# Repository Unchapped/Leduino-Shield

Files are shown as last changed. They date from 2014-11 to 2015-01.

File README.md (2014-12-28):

Leduino Shield
=======
The Leduino shield is a high-current PWM driver for commonly available 12V Tri-color LED strips and Modules. It is based on the [Adafruit PWM Servo Shield](http://www.adafruit.com/product/1411) and is compatible with their drivers. Some Library components were also sourced from the Sparkfun EAGLE Libraries.

Links
======
* [Adafruit Shield PCB](/adafruit/Adafruit-16-channel-PWM-Servo-Shield/)
* [Adafruit PWM Library](/adafruit/Adafruit-PWM-Servo-Driver-Library)
* [Adafruit EAGLE Library](/adafruit/Adafruit-Eagle-Library)
* [Sparkfun EAGLE Library](/sparkfun/SparkFun-Eagle-Libraries)

License
======
<br /><span xmlns:dct="http://purl.org/dc/terms/" property="dct:title">Leduino Shield</span> by <a xmlns:cc="http://creativecommons.org/ns#" href="https://github.com/Unchapped/Leduino" property="cc:attributionName" rel="cc:attributionURL">Nathaniel Chapman</a> is licensed under a <a rel="license" href="http://creativecommons.org/licenses/by-sa/4.0/">Creative Commons Attribution-ShareAlike 4.0 International License</a>.<br />Based on a work by <a xmlns:dct="http://purl.org/dc/terms/" href="http://www.adafruit.com/product/1411" rel="dct:source">Adafruit Industries</a>.

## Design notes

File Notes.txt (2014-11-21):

External Driver setup in PCA9685 datasheet table 11
Using setup [3] with NMOS drivers, no pullup resistors needed.

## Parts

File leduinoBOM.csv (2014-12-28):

Part | Value | Device | Package | Description | Qty/board | Digikey PN | Digikey Cost | Cost/Board
C1-2 | 10uF | CAP_POL1206 | EIA3216 | Capacitor Polarized | 2 | 1276-1804-1-ND | $0.34 | $0.68
C3 | .1uF | C-USC0805 | C0805 | CAPACITOR, American symbol | 2 | 1276-1099-1-ND | $0.10 | $0.20
JP1/2 | M023.5MM | M04-3.5MM | SCREWTERMINAL-3.5MM-4 |  | 1 | ED2637-ND | $0.73 | $0.73
JP4-7 |  | PINHD-1X63.5MM-RA | 1X06-3.5M-RA | TERM BLOCK HDR 6POS R/A 3.5MM | 4 | WM7774-ND | $1.54 | $6.16
JP4-7 | (Mating Conn) | PINHD-1X63.5MM-RA | 1X06-3.5M-RA | TERM BLOCK PLUG 6POS STR 3.5MM | 4 | WM7736-ND | $2.24 | $8.96
RN1-2 | 10K | 4R-NEXB38V | EXB38V | Array Chip Resistor | 2 | Y9103CT-ND | $0.12 | $0.24
S1 | SHIELD | PINHD-1x40-0.1" | CONN HEADR BRKWAY .100 40POS STR |  | 1 | A32701-40-ND | $3.01 | $3.01
U1 | MIC39100-5.0WS | V_REG_LDOSMD | SOT-223 | Voltage Regulator LDO | 1 | 576-1173-ND | $1.66 | $1.66
U2 |  | PCA9685 | TSSOP28 | PCA9685 - 16 Channel 12-Bit I2C PWM Controller | 1 | 568-8366-5-ND | $2.36 | $2.36
U3-10 | DMN6040SSD | DMN6040SSD | SO8 | MOSFET 2N-CH 60V 5A 8SO | 8 | DMN6040SSD-13DICT-ND | $0.46 | $3.68
 |  |  |  |  |  |  | Total: | $27.68
SOL |  |  | SOLDER PASTE NO-CLEAN LF 5CC SYR | Solder Paste |  | SMD291SNL-ND | $15.30
FLUX |  |  | TACK FLUX 10CC WATER WASHABLE | Solder Flux, Organic |  | SMD4300TF10-ND | $14.93
BRAID |  |  | BRAID ROSIN GOLD .050"X5' | Solder Braid |  | EB1087-ND | $2.77

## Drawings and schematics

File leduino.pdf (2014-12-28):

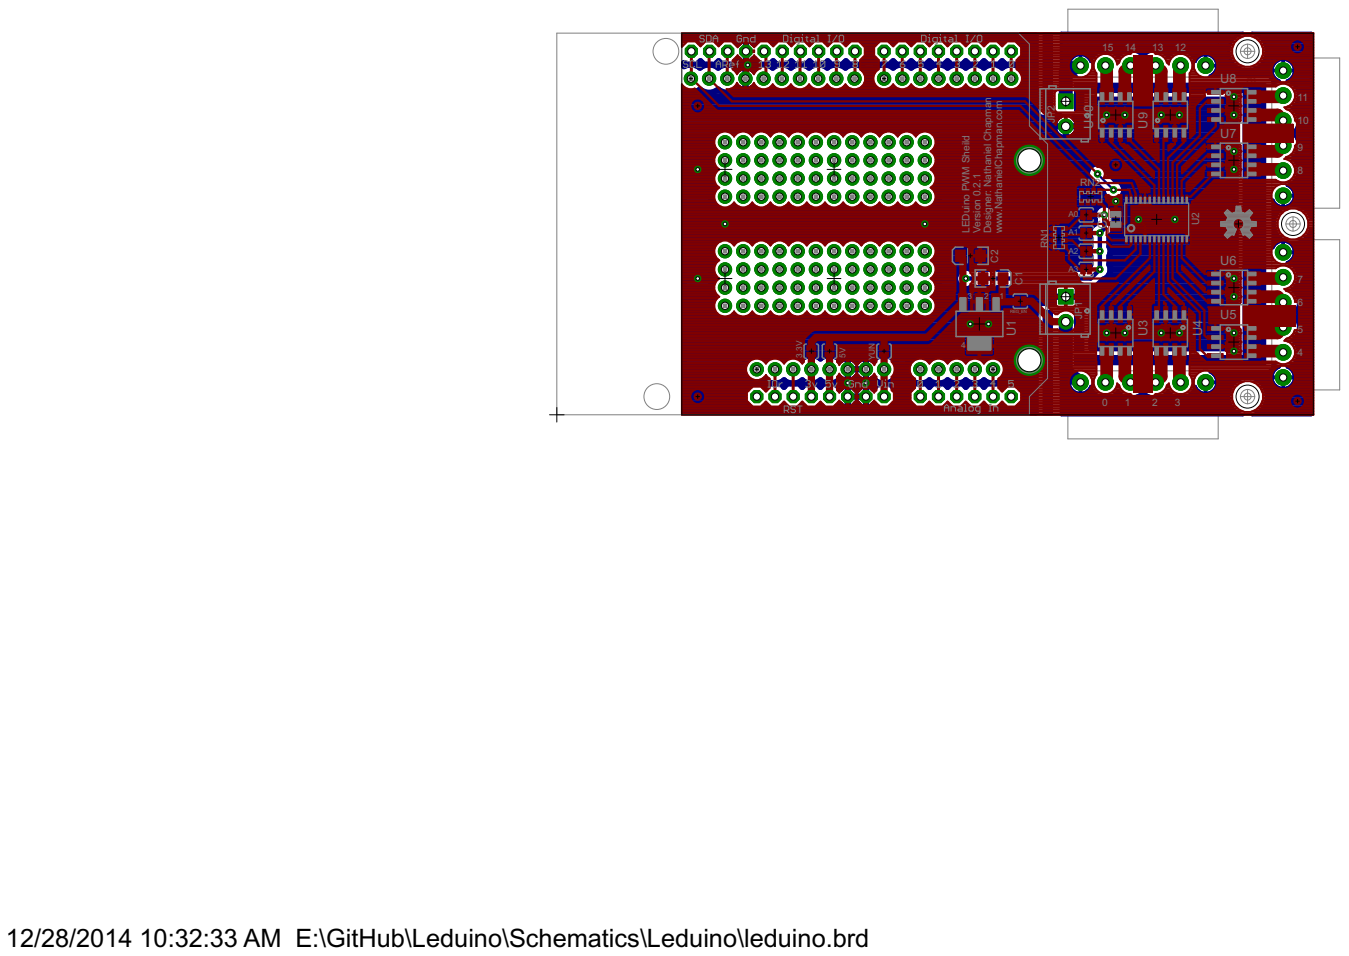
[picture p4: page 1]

LEDuino PWM Sheild Version 0.2.1 Designer: Nathaniel Chapman w .NathanielChapman.com

12/28/2014 10:32:33 AM E:\GitHub\Leduino\Schematics\Leduino\leduino.brd

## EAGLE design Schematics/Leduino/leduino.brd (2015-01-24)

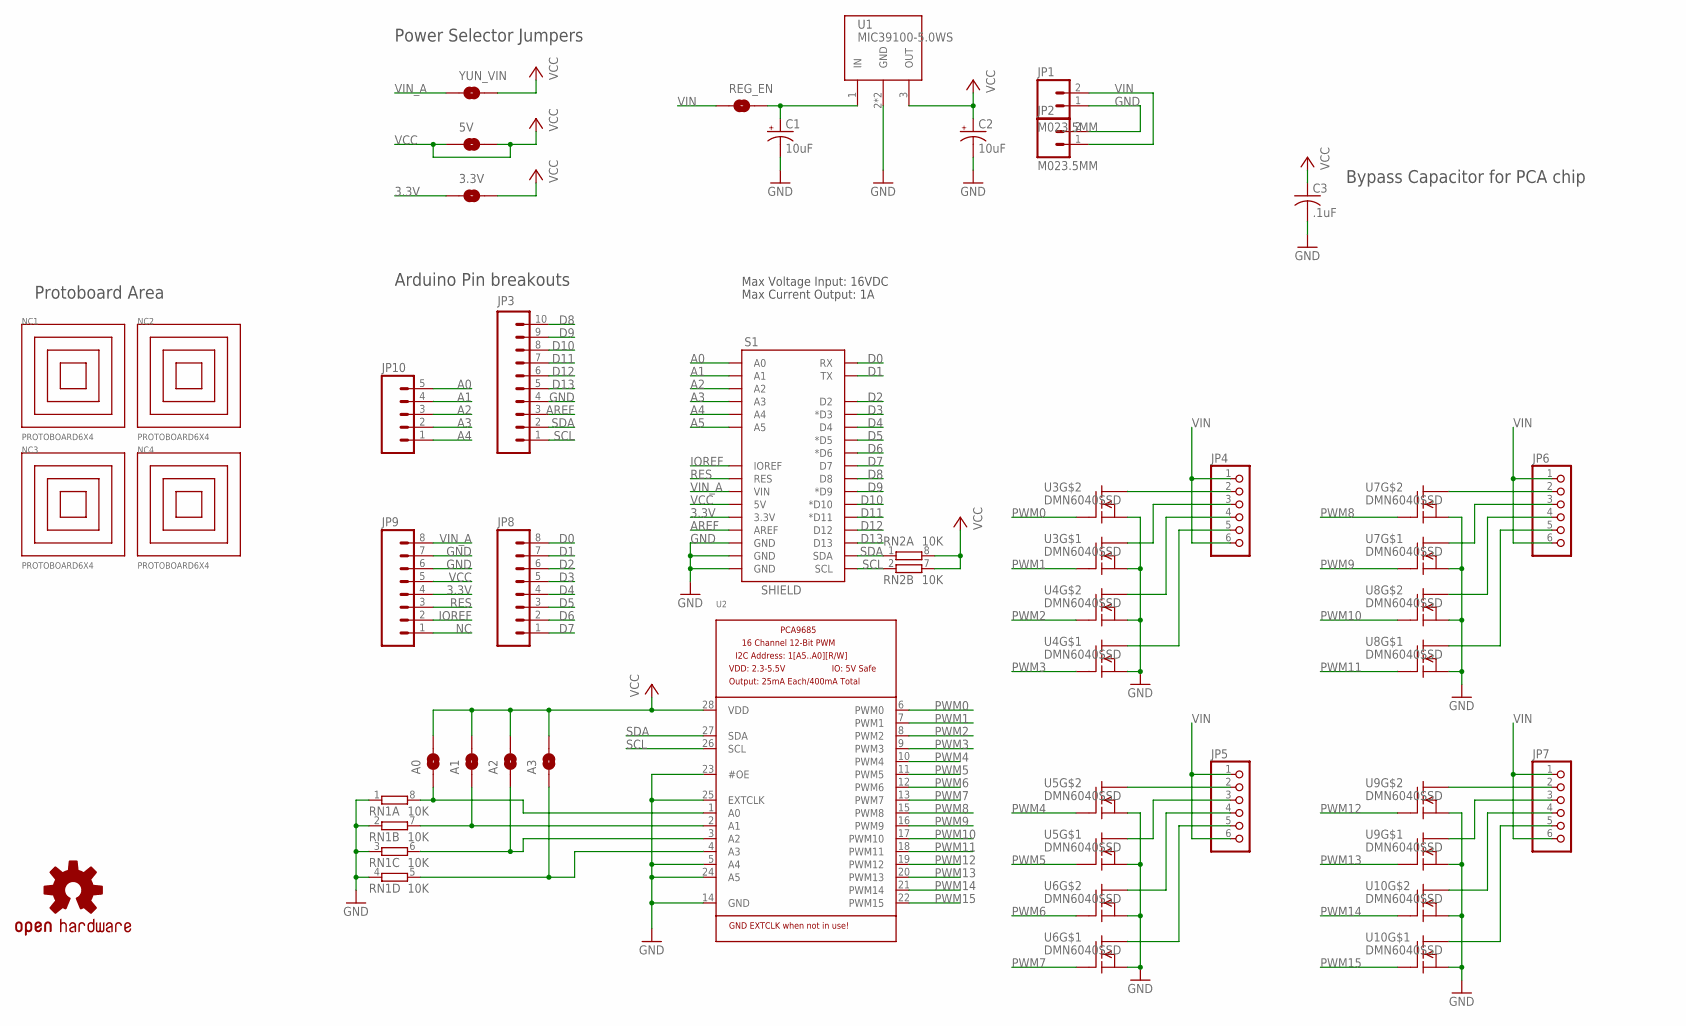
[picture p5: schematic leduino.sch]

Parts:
3.3V, 5V: SOLDERJUMPERNO; SJ_2S-NO
A0, A1, A2, A3: SOLDERJUMPERNO; SJ_2S-NO
C1, C2: 10uF; EIA3216
C3: .1uF; C0805
JP1, JP2: M023.5MM; SCREWTERMINAL-3.5MM-2
JP3: M10NO_SILK_PTH_FEMALE; 1X10_NO_SILK
JP4, JP5, JP6, JP7: PINHD-1X63.5MM-RA; 1X06-3.5M-RA
JP8, JP9: M08NO_SILK_FEMALE_PTH; 1X08_NO_SILK
JP10: M05NO_SILK; 1X05_NO_SILK
NC1, NC2, NC3, NC4: PROTOBOARD6X4; PROTOBOARD_6X4
REG_EN: SOLDERJUMPERNO; SJ_2S-NO
RN1, RN2: 10K; EXB38V
S1: SHIELD; ARDUINOR3
U1: MIC39100-5.0WS; SOT223
U2: PCA9685; TSSOP28
U3, U4, U5, U6, U7, U8, U9, U10: DMN6040SSD; SO8
U$6: OSHW-LOGOM; OSHW-LOGO-M
YUN_VIN: SOLDERJUMPERNO; SJ_2S-NO

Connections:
3.3V: 3.3V.1, JP9.4, S1.3V (3.3V)
A0: JP10.5, S1.A0
A1: JP10.4, S1.A1
A2: JP10.3, S1.A2
A3: JP10.2, S1.A3
A4: JP10.1, S1.A4
A5: S1.A5
AREF: JP3.3, S1.AREF
D0: JP8.8, S1.D0 (RX)
D1: JP8.7, S1.D1 (TX)
D2: JP8.6, S1.D2
D3: JP8.5, S1.D3 (*D3)
D4: JP8.4, S1.D4
D5: JP8.3, S1.D5 (*D5)
D6: JP8.2, S1.D6 (*D6)
D7: JP8.1, S1.D7
D8: JP3.10, S1.D8
D9: JP3.9, S1.D9 (*D9)
D10: JP3.8, S1.D10 (*D10)
D11: JP3.7, S1.D11 (*D11)
D12: JP3.6, S1.D12
D13: JP3.5, S1.D13
GND: C1.C (-), C2.C (-), C3.2, JP1.1, JP2.2, JP3.4, JP9.6, JP9.7, RN1.1, RN1.2 (1), RN1.3 (1), RN1.4 (1), S1.GND, S1.GND1 (GND), S1.GND2 (GND), U1.2 (GND), U1.4 (GND), U2.5 (A4), U2.14 (GND), U2.23 (#OE), U2.24 (A5), U2.25 (EXTCLK), U3.1 (S), U3.3 (S), U4.1 (S), U4.3 (S), U5.1 (S), U5.3 (S), U6.1 (S), U6.3 (S), U7.1 (S), U7.3 (S), U8.1 (S), U8.3 (S), U9.1 (S), U9.3 (S), U10.1 (S), U10.3 (S)
IOREF: JP9.2, S1.IOREF
unnamed: JP4.2, U3.5 (D), U3.6 (D)
unnamed: JP4.3, U3.7 (D), U3.8 (D)
unnamed: JP4.5, U4.7 (D), U4.8 (D)
unnamed: JP4.4, U4.5 (D), U4.6 (D)
unnamed: JP7.2, U9.5 (D), U9.6 (D)
unnamed: JP7.3, U9.7 (D), U9.8 (D)
unnamed: JP7.5, U10.7 (D), U10.8 (D)
unnamed: JP7.4, U10.5 (D), U10.6 (D)
unnamed: JP5.2, U5.5 (D), U5.6 (D)
unnamed: JP5.3, U5.7 (D), U5.8 (D)
unnamed: JP5.5, U6.7 (D), U6.8 (D)
unnamed: JP5.4, U6.5 (D), U6.6 (D)
unnamed: C1.A (+), REG_EN.2, U1.1 (IN)
unnamed: A3.1, RN1.5 (2), U2.4 (A3)
unnamed: A0.1, RN1.8 (2), U2.1 (A0)
unnamed: A1.1, RN1.7 (2), U2.2 (A1)
unnamed: JP6.2, U7.5 (D), U7.6 (D)
unnamed: JP6.3, U7.7 (D), U7.8 (D)
unnamed: JP6.5, U8.7 (D), U8.8 (D)
unnamed: JP6.4, U8.5 (D), U8.6 (D)
unnamed: A2.1, RN1.6 (2), U2.3 (A2)
NC: JP9.1
PWM0: U2.6 (PWM0), U3.4 (G)
PWM1: U2.7 (PWM1), U3.2 (G)
PWM2: U2.8 (PWM2), U4.4 (G)
PWM3: U2.9 (PWM3), U4.2 (G)
PWM4: U2.10 (PWM4), U5.4 (G)
PWM5: U2.11 (PWM5), U5.2 (G)
PWM6: U2.12 (PWM6), U6.4 (G)
PWM7: U2.13 (PWM7), U6.2 (G)
PWM8: U2.15 (PWM8), U7.4 (G)
PWM9: U2.16 (PWM9), U7.2 (G)
PWM10: U2.17 (PWM10), U8.4 (G)
PWM11: U2.18 (PWM11), U8.2 (G)
PWM12: U2.19 (PWM12), U9.4 (G)
PWM13: U2.20 (PWM13), U9.2 (G)
PWM14: U2.21 (PWM14), U10.4 (G)
PWM15: U2.22 (PWM15), U10.2 (G)
RES: JP9.3, S1.RESET (RES)
SCL: JP3.1, RN2.2 (1), S1.SCL, U2.26 (SCL)
SDA: JP3.2, RN2.1, S1.SDA, U2.27 (SDA)
VCC: 3.3V.2, 5V.1, 5V.2, A0.2, A1.2, A2.2, A3.2, C2.A (+), C3.1, JP9.5, RN2.7 (2), RN2.8 (2), S1.5V, U1.3 (OUT), U2.28 (VDD), YUN_VIN.2
VIN: JP1.2, JP2.1, JP4.1, JP4.6, JP5.1, JP5.6, JP6.1, JP6.6, JP7.1, JP7.6, REG_EN.1
VIN_A: JP9.8, S1.VIN, YUN_VIN.1

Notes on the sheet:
Max Voltage Input: 16VDC
Max Current Output: 1A
Power Selector Jumpers
Bypass Capacitor for PCA chip
Arduino Pin breakouts
Protoboard Area

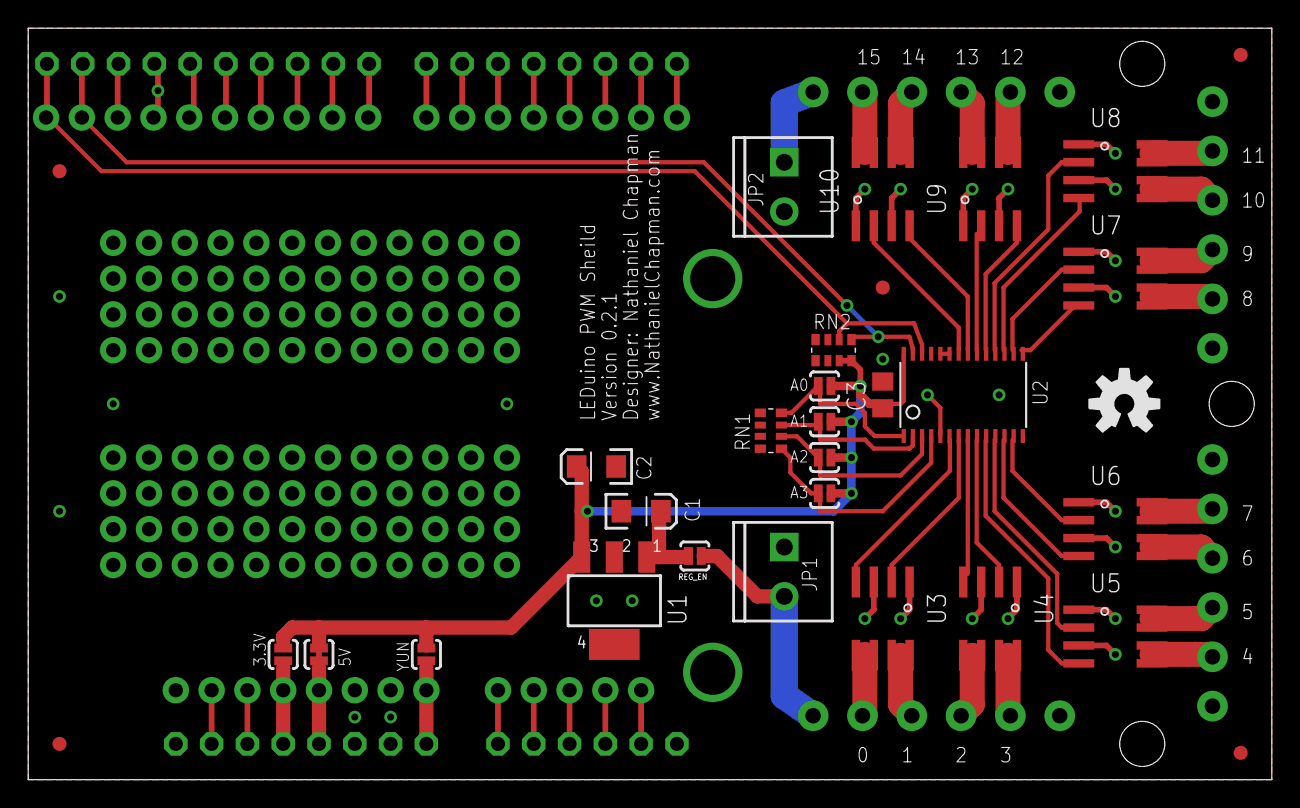
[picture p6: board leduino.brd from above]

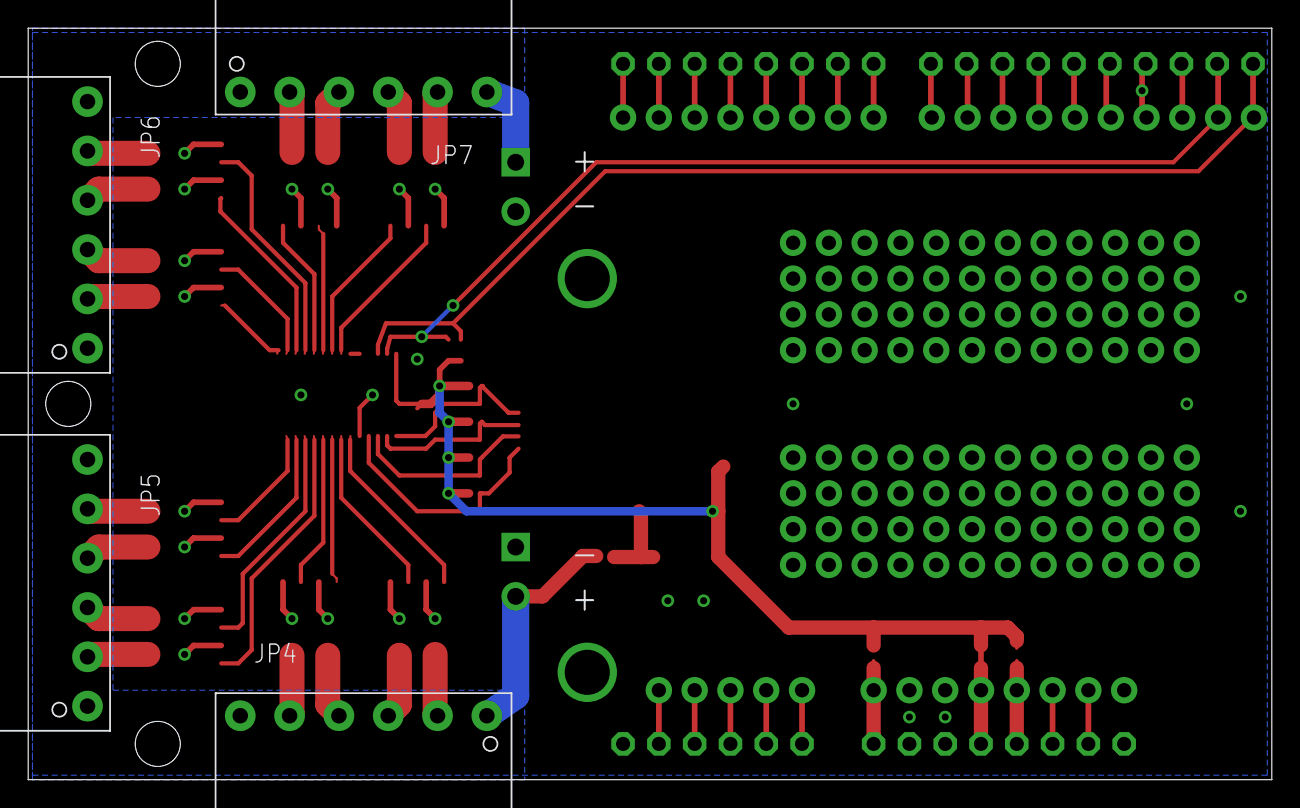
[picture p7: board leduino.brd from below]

Board: 2 copper layers, 88.3 x 53.3 mm, 44 parts (4 on the bottom side), 66 nets.

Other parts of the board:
U$1, U$2, U$3, U$4, U$5: FIDUCIAL-1X2

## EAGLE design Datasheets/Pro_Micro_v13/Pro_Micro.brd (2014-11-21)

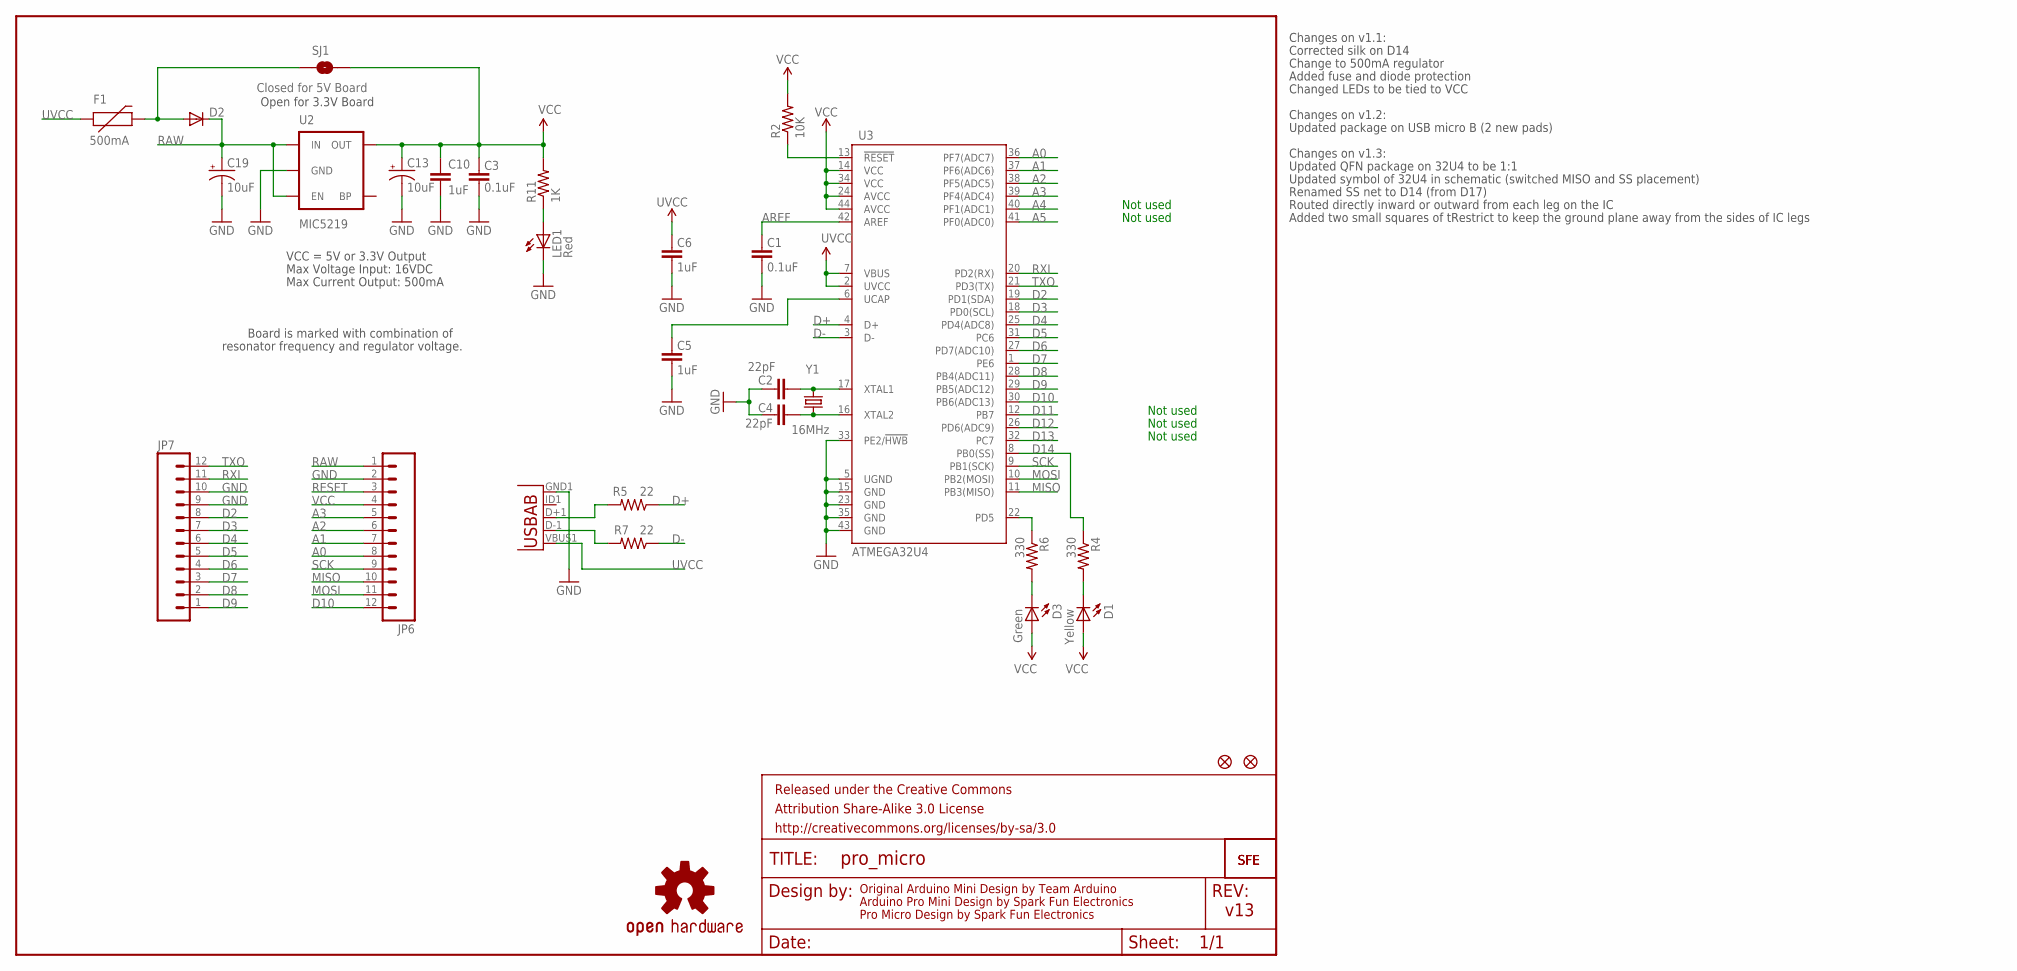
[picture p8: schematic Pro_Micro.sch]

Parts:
C1, C3: 0.1uF; 0603-CAP
C2, C4: 22pF; 0603-CAP
C5, C6, C10: 1uF; 0603-CAP
C13, C19: 10uF; EIA3216
D1: Yellow; LED-0603
D2: DIODESOD; SOD-323
D3: Green; LED-0603
F1: 500mA; PTC-1206
FRAME1: FRAME-LETTER; CREATIVE_COMMONS
JP1, JP2: FIDUCIALUFIDUCIAL; MICRO-FIDUCIAL
JP6, JP7: M12PTH; 1X12
LED1: Red; LED-0603
R2: 10K; 0603-RES
R4, R6: 330; 0603-RES
R5, R7: 22; 0603-RES
R11: 1K; 0603-RES
SJ1: Closed for 5V Board; SJ_2S
U2: MIC5219; SOT23-5
U3: ATMEGA32U4; QFN-44-NOPAD_1:1-OUTFAKES
U$1: LOGO-SFESK; SFE-LOGO-FLAME
U$3: OSHW-LOGOS; OSHW-LOGO-S
U$11: LOGO-SFENEW; SFE-NEW-WEBLOGO
X1: USB-ABIN&OUT; USB-AB-MICRO-SMD-V03-IN&OUT
Y1: 16MHz; CRYSTAL-SMD-5X3

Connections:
A0: JP6.8, U3.36 (PF7(ADC7))
A1: JP6.7, U3.37 (PF6(ADC6))
A2: JP6.6, U3.38 (PF5(ADC5))
A3: JP6.5, U3.39 (PF4(ADC4))
A4: U3.40 (PF1(ADC1))
A5: U3.41 (PF0(ADC0))
AREF: C1.2, U3.42 (AREF)
D2: JP7.8, U3.19 (PD1(SDA))
D3: JP7.7, U3.18 (PD0(SCL))
D4: JP7.6, U3.25 (PD4(ADC8))
D5: JP7.5, U3.31 (PC6)
D6: JP7.4, U3.27 (PD7(ADC10))
D7: JP7.3, U3.1 (PE6)
D8: JP7.2, U3.28 (PB4(ADC11))
D9: JP7.1, U3.29 (PB5(ADC12))
D10: JP6.12, U3.30 (PB6(ADC13))
D11: U3.12 (PB7)
D12: U3.26 (PD6(ADC9))
D13: U3.32 (PC7)
D14: R4.1, U3.8 (PB0(SS))
D+: R5.1, U3.4 (D+)
D-: R7.1, U3.3 (D-)
GND: C1.1, C2.2, C3.1, C4.2, C5.1, C6.1, C10.2, C13.C (-), C19.C (-), JP6.2, JP7.9, JP7.10, LED1.C, U2.2 (GND), U3.5 (UGND), U3.15 (GND), U3.23 (GND), U3.33 (PE2/!HWB), U3.35 (GND), U3.43 (GND), X1.GND1 (GND)
MISO: JP6.10, U3.11 (PB3(MISO))
MOSI: JP6.11, U3.10 (PB2(MOSI))
unnamed: C4.1, U3.16 (XTAL2), Y1.1
unnamed: C2.1, U3.17 (XTAL1), Y1.3 (2)
unnamed: D2.2 (A), F1.2, SJ1.1
unnamed: C5.2, U3.6 (UCAP)
unnamed: D1.C, R4.2
unnamed: R7.2, X1.D-1 (D-)
unnamed: D3.C, R6.2
unnamed: R5.2, X1.D+1 (D+)
unnamed: LED1.A, R11.1
RAW: C19.A (+), D2.1 (C), JP6.1, U2.1 (IN), U2.3 (EN)
RESET: JP6.3, R2.1, U3.13 (!RESET)
RXI: JP7.11, U3.20 (PD2(RX))
SCK: JP6.9, U3.9 (PB1(SCK))
TXLED: R6.1, U3.22 (PD5)
TXO: JP7.12, U3.21 (PD3(TX))
UVCC: C6.2, F1.1, U3.2 (UVCC), U3.7 (VBUS), X1.VBUS1 (VBUS)
VCC: C3.2, C10.1, C13.A (+), D1.A, D3.A, JP6.4, R2.2, R11.2, SJ1.2, U2.5 (OUT), U3.14 (VCC), U3.24 (AVCC), U3.34 (VCC), U3.44 (AVCC)

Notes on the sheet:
Original Arduino Mini Design by Team Arduino
Arduino Pro Mini Design by Spark Fun Electronics
Max Voltage Input: 16VDC
Max Current Output: 500mA
Board is marked with combination of
resonator frequency and regulator voltage.
VCC = 5V or 3.3V Output
Not used
Pro Micro Design by Spark Fun Electronics
Changes on v1.1:
Corrected silk on D14
Change to 500mA regulator
Open for 3.3V Board
Added fuse and diode protection
Changed LEDs to be tied to VCC
Changes on v1.2:
Updated package on USB micro B (2 new pads)
Changes on v1.3:
Updated QFN package on 32U4 to be 1:1
Updated symbol of 32U4 in schematic (switched MISO and SS placement)
Renamed SS net to D14 (from D17)
Routed directly inward or outward from each leg on the IC
Added two small squares of tRestrict to keep the ground plane away from the sides of IC legs
v13

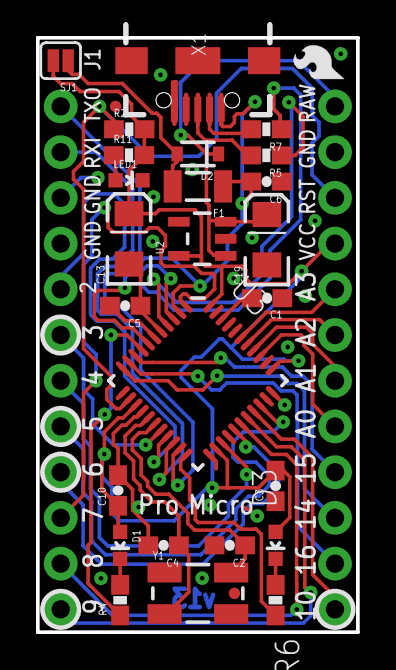
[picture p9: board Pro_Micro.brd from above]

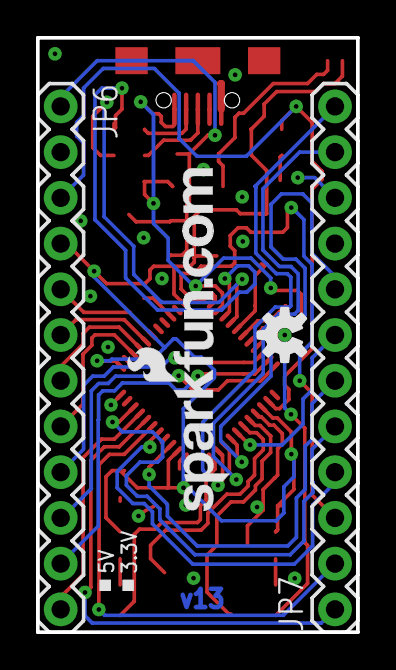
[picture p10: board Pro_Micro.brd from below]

Board: 2 copper layers, 17.8 x 33.0 mm, 33 parts (4 on the bottom side), 37 nets.

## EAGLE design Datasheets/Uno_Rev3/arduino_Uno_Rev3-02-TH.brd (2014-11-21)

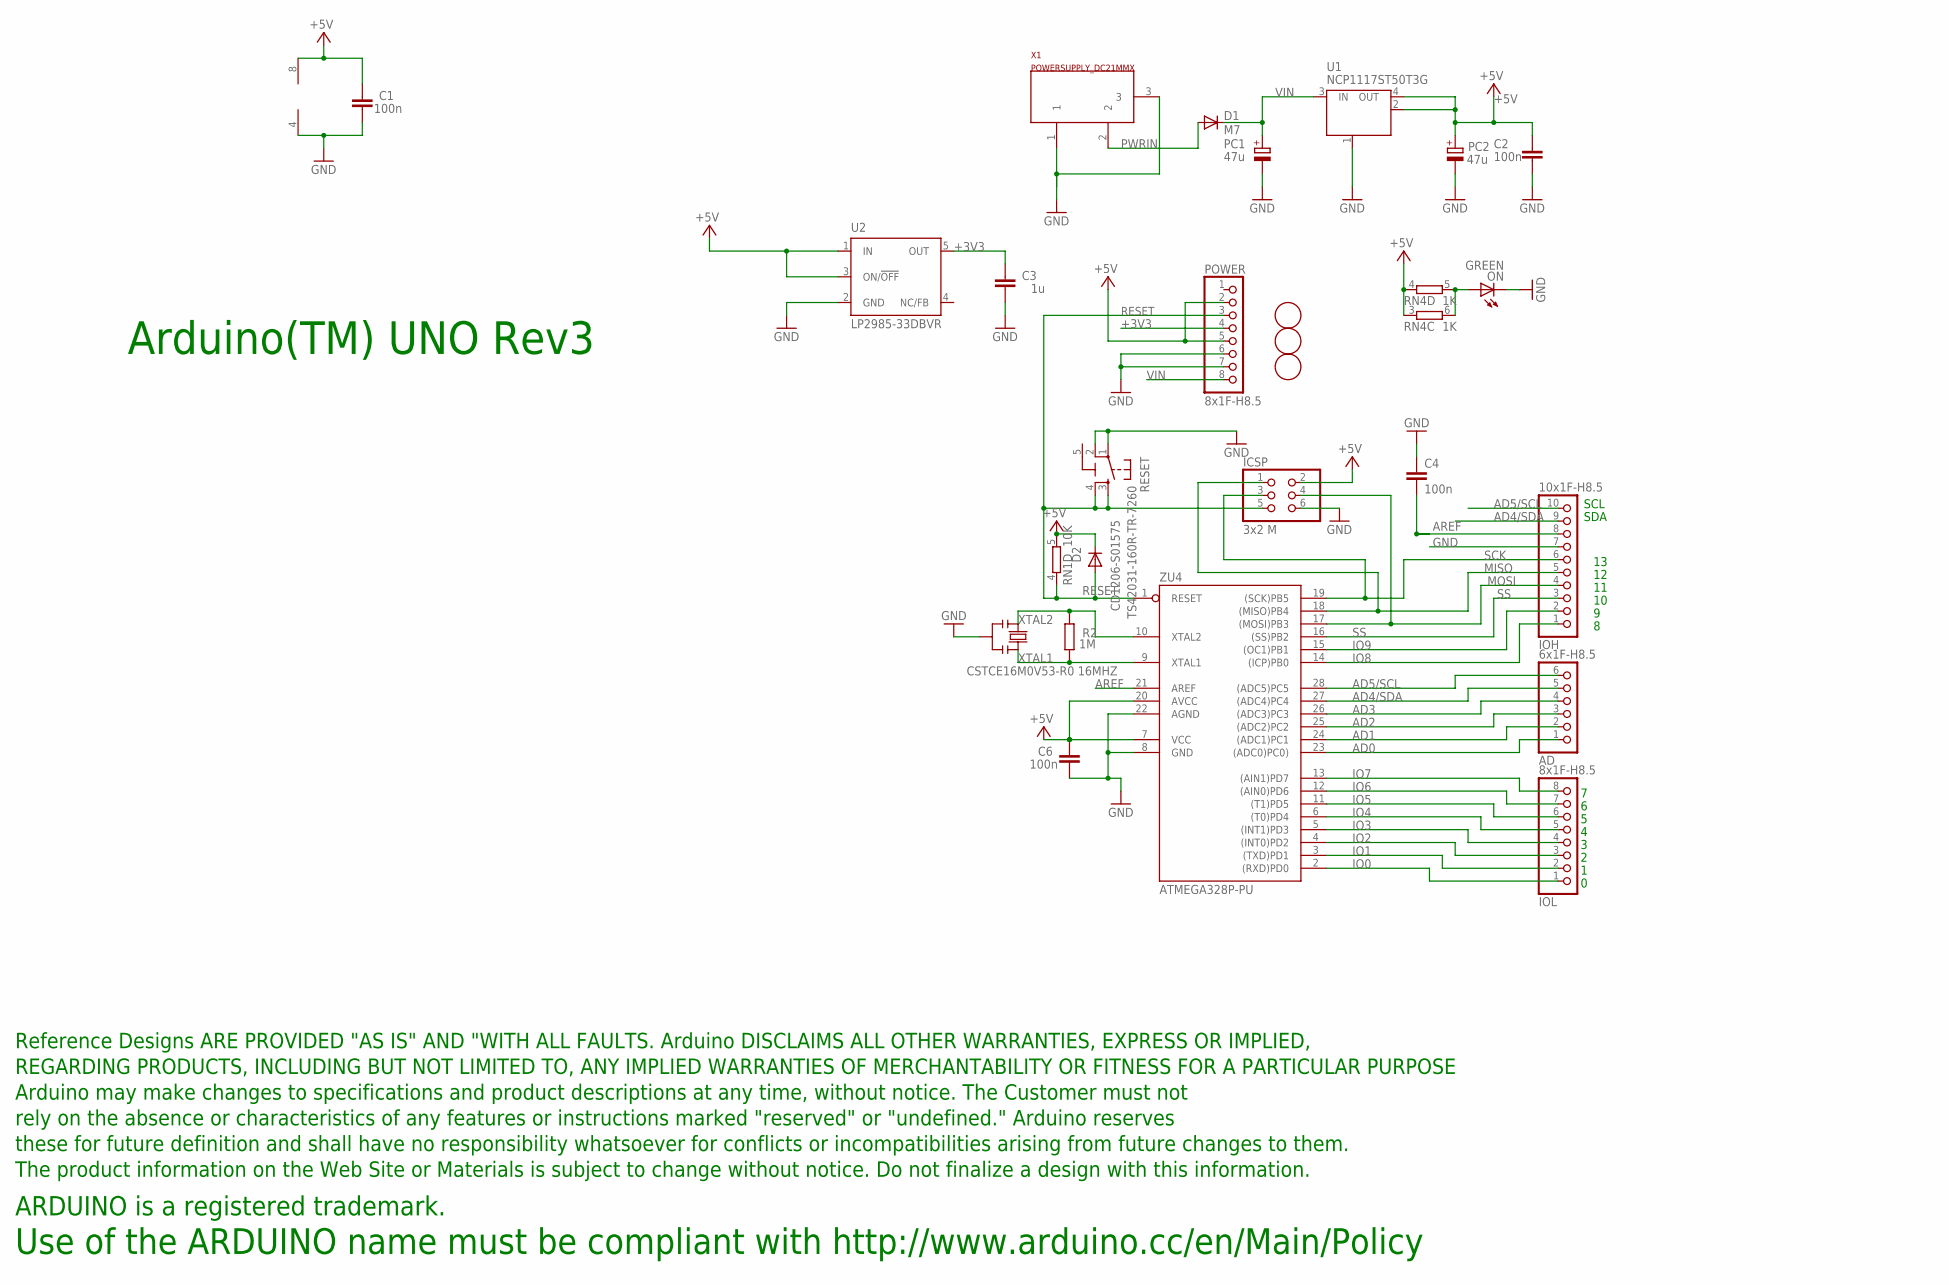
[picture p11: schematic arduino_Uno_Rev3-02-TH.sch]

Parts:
AD: 6x1F-H8.5; 1X06
C1, C2, C4, C6: 100n; C0603-ROUND
C3: 1u; C0603-ROUND
D1: M7; SMB
D2: CD1206-S01575; MINIMELF
FD1, FD2, FD3: FIDUCIALMOUNT; FIDUCIA-MOUNT
ICSP: 3x2 M; 2X03
IOH: 10x1F-H8.5; 1X10
IOL: 8x1F-H8.5; 1X08
ON: GREEN; CHIP-LED0805
PC1, PC2: 47u; PANASONIC_D
POWER: 8x1F-H8.5; 1X08
R2: 1M; R0603-ROUND
RESET: TS42031-160R-TR-7260; TS42
RN1: 10K; CAY16
RN4: 1K; CAY16
U1: NCP1117ST50T3G; SOT223
U2: LP2985-33DBVR; SOT23-DBV
U5: LMV358IDGKR; MSOP08
U$1: DISCLAIMER
X1: POWERSUPPLY_DC21MMX; POWERSUPPLY_DC-21MM
Y2: CSTCE16M0V53-R0 16MHZ; RESONATOR
ZU4: ATMEGA328P-PU; DIL28-3

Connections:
5-GND: RESET.5 (5-GND)
+3V3: C3.2, POWER.4, U2.5 (OUT)
+5V: C1.2, C2.2, C6.2, D2.C, ICSP.2, PC2.+, POWER.2, POWER.5, RN1.5 (2), RN4.3 (1), RN4.4 (1), U1.2 (OUT), U1.4 (OUT), U2.1 (IN), U2.3 (ON/!OFF), U5.8 (V+), ZU4.7 (VCC), ZU4.20 (AVCC)
AD0: AD.1, ZU4.23 ((ADC0)PC0))
AD1: AD.2, ZU4.24 ((ADC1)PC1)
AD2: AD.3, ZU4.25 ((ADC2)PC2)
AD3: AD.4, ZU4.26 ((ADC3)PC3)
AD4/SDA: AD.5, IOH.9, ZU4.27 ((ADC4)PC4)
AD5/SCL: AD.6, IOH.10, ZU4.28 ((ADC5)PC5)
AREF: C4.2, IOH.8, ZU4.21 (AREF)
GND: C1.1, C2.1, C3.1, C4.1, C6.1, ICSP.6, IOH.7, ON.C, PC1.-, PC2.-, POWER.6, POWER.7, RESET.1, RESET.2, U1.1 (GND/ADJ), U2.2 (GND), U5.4 (V-), X1.1, X1.3, Y2.2, ZU4.8 (GND), ZU4.22 (AGND)
IO0: IOL.1, ZU4.2 ((RXD)PD0)
IO1: IOL.2, ZU4.3 ((TXD)PD1)
IO2: IOL.3, ZU4.4 ((INT0)PD2)
IO3: IOL.4, ZU4.5 ((INT1)PD3)
IO4: IOL.5, ZU4.6 ((T0)PD4)
IO5: IOL.6, ZU4.11 ((T1)PD5)
IO6: IOL.7, ZU4.12 ((AIN0)PD6)
IO7: IOL.8, ZU4.13 ((AIN1)PD7)
IO8: IOH.1, ZU4.14 ((ICP)PB0)
IO9: IOH.2, ZU4.15 ((OC1)PB1)
MISO: ICSP.1, IOH.5, ZU4.18 ((MISO)PB4)
MOSI: ICSP.4, IOH.4, ZU4.17 ((MOSI)PB3)
unnamed: ON.A, RN4.5 (2), RN4.6 (2)
PWRIN: D1.A, X1.2
RESET: D2.A, ICSP.5, POWER.3, RESET.3, RESET.4, RN1.4 (1), ZU4.1 (RESET)
SCK: ICSP.3, IOH.6, ZU4.19 ((SCK)PB5)
SS: IOH.3, ZU4.16 ((SS)PB2)
VIN: D1.C, PC1.+, POWER.8, U1.3 (IN)
XTAL1: R2.1, Y2.3, ZU4.9 (XTAL1)
XTAL2: R2.2, Y2.1, ZU4.10 (XTAL2)

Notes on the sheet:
Arduino(TM) UNO Rev3
SDA
SCL
Use of the ARDUINO name must be compliant with http://www.arduino.cc/en/Main/Policy

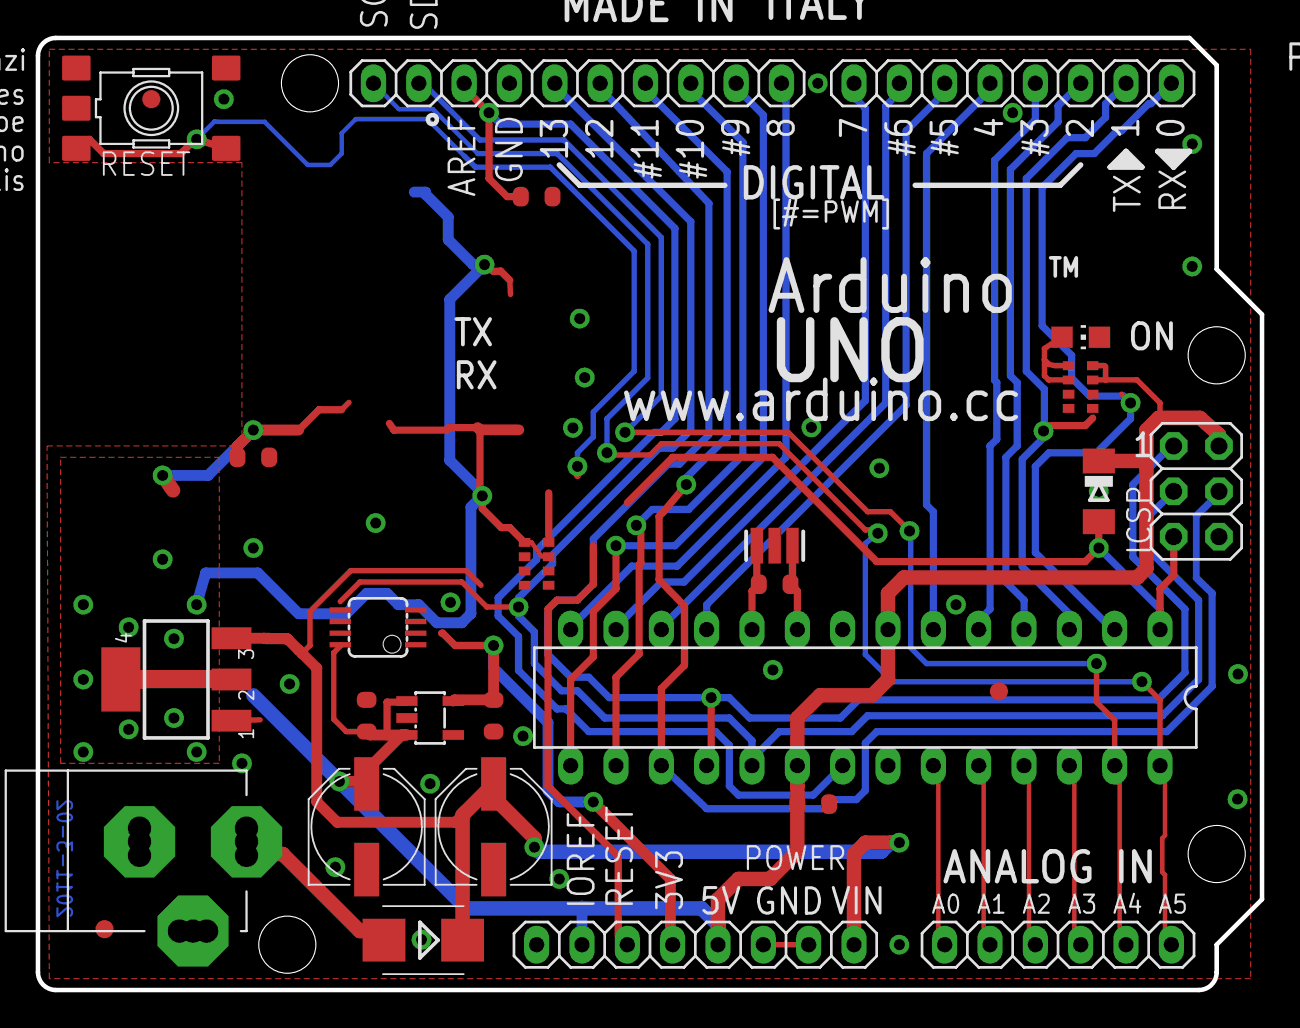
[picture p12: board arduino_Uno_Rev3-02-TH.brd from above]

Board: 2 copper layers, 68.6 x 53.3 mm, 29 parts (0 on the bottom side), 30 nets.

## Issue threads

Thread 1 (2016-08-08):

Linear Regulator for 12V to 5V is a fire risk

Unchapped, 2016-08-08:
because Holy crap does that thing get hot! replace with a switching regulator.

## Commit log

2014-11-21 Commit of work so far before switching to Yun Sheild
    [Pro_Micro.brd, Pro_Micro.sch, arduino_Uno_Rev3-02-TH.brd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]
2014-11-21 Making progress, attempting to hack the autorouter
    [leduino.brd, leduino.sch]
2014-11-21 Finished Layout, cleared DRC
    [leduino.brd, leduino.sch]
2014-11-22 Cleaned up silkscreen, passed freedDFM
    [Pro_Micro.brd, Pro_Micro.sch, arduino_Uno_Rev3-02-TH.brd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]
2014-11-22 Added Panelized gerbers and BOM
    [layout.cfg, leduinoBOM.csv, leduinoBOM.xlsx]
2014-12-27 BOM updates
    [leduinoBOM.csv]
2014-12-28 Designed and Laid out Board Rev 2.0 ready for review
    [leduino.brd, leduino.sch]
2014-12-28 Finished v2 update, ready for lbr cleanup
    [leduino.brd, leduino.sch]
2014-12-28 Cleaned up old build artifacts
    [layout.cfg]
2014-12-28 Changed board text to match CC-SA wording, updated BOM
    [leduino.brd, leduinoBOM.csv, leduinoBOM.xlsx]
2015-01-24 Fixed Hole diameter in 3.5 mm Molex Connector
    [leduino.brd, leduino.sch]

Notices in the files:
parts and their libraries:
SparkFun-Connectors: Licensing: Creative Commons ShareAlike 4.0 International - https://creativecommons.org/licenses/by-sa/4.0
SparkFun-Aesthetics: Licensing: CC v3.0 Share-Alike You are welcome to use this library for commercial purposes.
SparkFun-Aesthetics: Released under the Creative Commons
